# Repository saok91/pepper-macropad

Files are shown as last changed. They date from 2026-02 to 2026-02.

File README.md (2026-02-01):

# pepper – Custom Macropad PCB

This repository contains the **source design files** for **pepper**, a custom mechanical macropad designed using **KiCad**.

## Repository Contents

### Source files (tracked)
These files are the **source of truth** for the design and are version-controlled:

- `pepper.kicad_sch` – Schematic
- `pepper.kicad_pcb` – PCB layout
- `pepper.kicad_pro` – KiCad project configuration

### Generated files (ignored)
The following files are intentionally **not tracked** via `.gitignore`:

- 3D exports: `*.stl`, `*.step`, `*.stp`, `*.wrl`, `*.obj`
- Fabrication outputs: Gerbers, drills, pick-and-place files
- KiCad autosave, backup, and cache files
- BOM exports (`.csv`, `.xlsx`)
- OS / editor temporary files

Generated outputs may be shared separately (e.g. releases) when the design is ready.

## Tools

- **EDA**: KiCad (v7+ recommended)
- **Version control**: Git

## Project Status

- Work in progress (WIP)
- Not yet released for manufacturing

## Notes

- This repository contains **design sources only**
- Do not manufacture or modify outputs without validating against the KiCad source files

## License

TBD

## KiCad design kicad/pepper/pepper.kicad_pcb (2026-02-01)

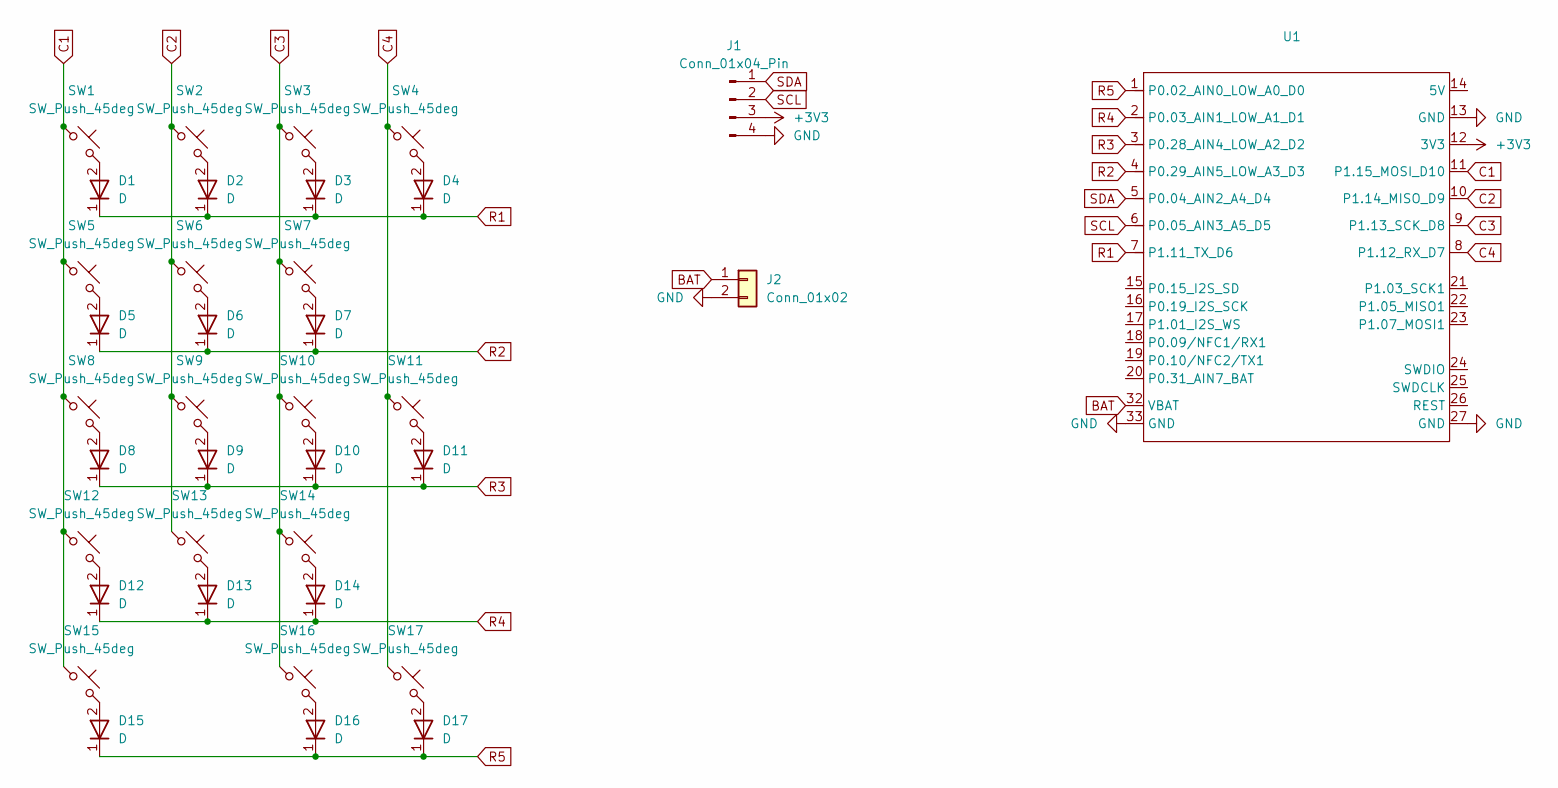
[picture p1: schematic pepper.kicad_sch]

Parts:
D1, D2, D3, D4, D5, D6, D7, D8, D9, D10, D11, D12, D13, D14, D15, D16, D17: D; D_SOD-123
J1: Conn_01x04_Pin; SSD1306
J2: Conn_01x02; JST_XH_S2B-XH-A_1x02_P2.50mm_Horizontal
SW1, SW2, SW3, SW4, SW5, SW6, SW7, SW8, SW9, SW10, SW12, SW13, SW14, SW16: SW_Push_45deg; MNP_SW_Hotswap_Kailh_MX_1.00u
SW11, SW17: SW_Push_45deg; MNP_SW_Hotswap_Kailh_MX_2.00u_90deg
SW15: SW_Push_45deg; MNP_SW_Hotswap_Kailh_MX_2.00u
U1: XIAO-nRF52840-Plus-SMD

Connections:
+3V3: J1.3, U1.12 (3V3)
BAT: J2.1, U1.32 (VBAT)
C1: SW1.1, SW5.1, SW8.1, SW12.1, SW15.1, U1.11 (P1.15_MOSI_D10)
C2: SW2.1, SW6.1, SW9.1, SW13.1, U1.10 (P1.14_MISO_D9)
C3: SW3.1, SW7.1, SW10.1, SW14.1, SW16.1, U1.9 (P1.13_SCK_D8)
C4: SW4.1, SW11.1, SW17.1, U1.8 (P1.12_RX_D7)
GND: J1.4, J2.2, U1.13 (GND), U1.27 (GND), U1.33 (GND)
unnamed: D1.2 (A), SW1.2
unnamed: D2.2 (A), SW2.2
unnamed: D3.2 (A), SW3.2
unnamed: D4.2 (A), SW4.2
unnamed: D5.2 (A), SW5.2
unnamed: D6.2 (A), SW6.2
unnamed: D7.2 (A), SW7.2
unnamed: D8.2 (A), SW8.2
unnamed: D9.2 (A), SW9.2
unnamed: D10.2 (A), SW10.2
unnamed: D11.2 (A), SW11.2
unnamed: D12.2 (A), SW12.2
unnamed: D13.2 (A), SW13.2
unnamed: D14.2 (A), SW14.2
unnamed: D15.2 (A), SW15.2
unnamed: D16.2 (A), SW16.2
unnamed: D17.2 (A), SW17.2
R1: D1.1 (K), D2.1 (K), D3.1 (K), D4.1 (K), U1.7 (P1.11_TX_D6)
R2: D5.1 (K), D6.1 (K), D7.1 (K), U1.4 (P0.29_AIN5_LOW_A3_D3)
R3: D8.1 (K), D9.1 (K), D10.1 (K), D11.1 (K), U1.3 (P0.28_AIN4_LOW_A2_D2)
R4: D12.1 (K), D13.1 (K), D14.1 (K), U1.2 (P0.03_AIN1_LOW_A1_D1)
R5: D15.1 (K), D16.1 (K), D17.1 (K), U1.1 (P0.02_AIN0_LOW_A0_D0)
SCL: J1.2, U1.6 (P0.05_AIN3_A5_D5)
SDA: J1.1, U1.5 (P0.04_AIN2_A4_D4)

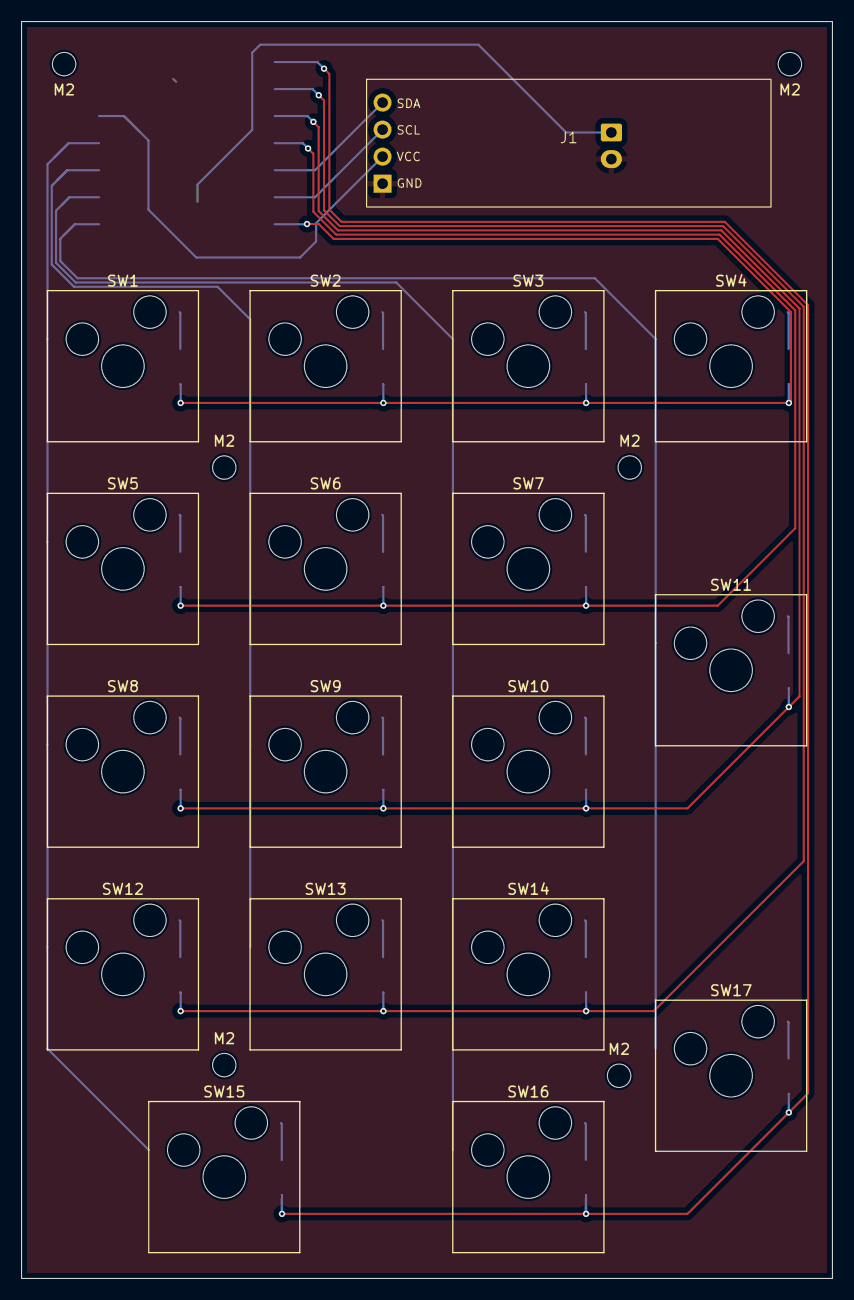
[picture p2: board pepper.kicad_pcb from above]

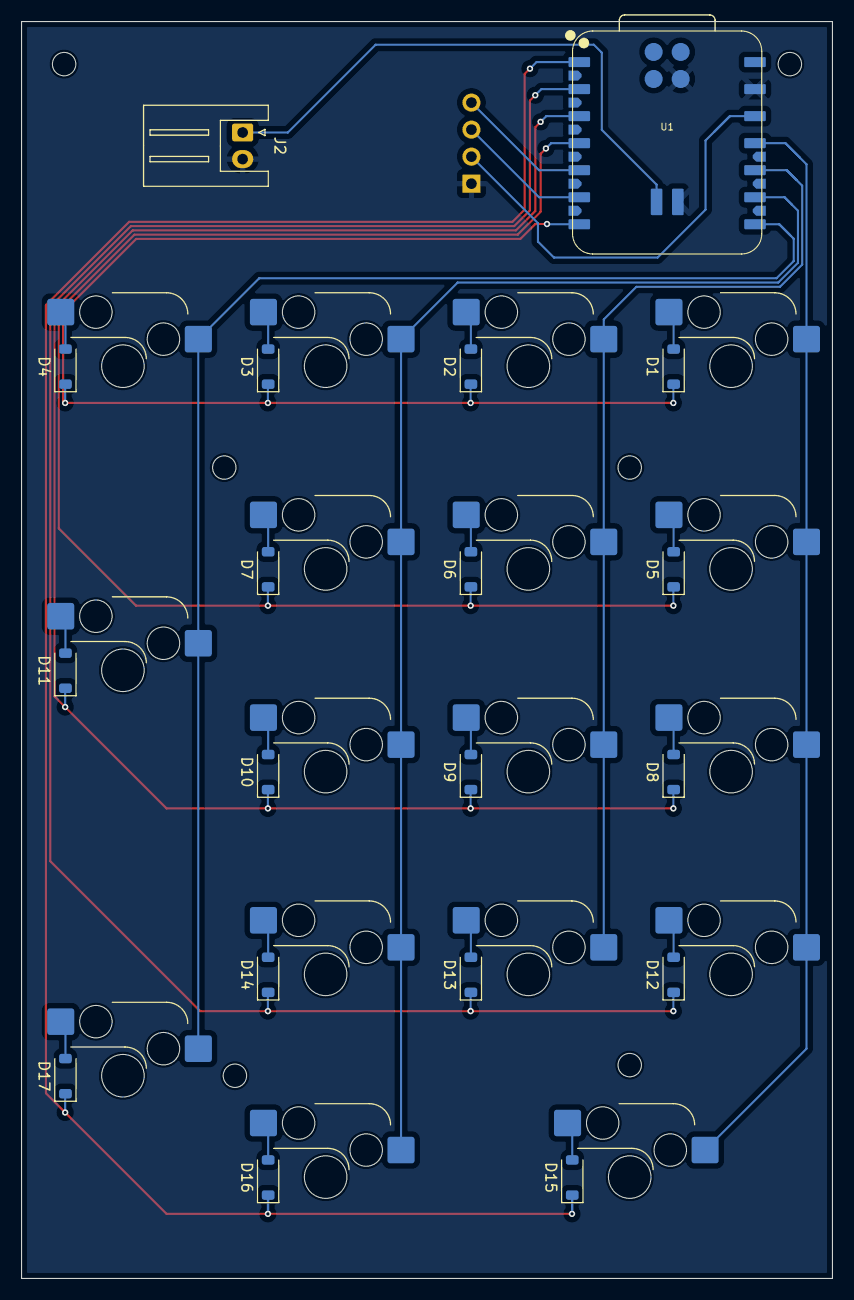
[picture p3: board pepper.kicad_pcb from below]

Board: 2 copper layers, 76.2 x 118.1 mm, 43 parts (19 on the bottom side), 31 nets.

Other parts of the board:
M2, M2#2, M2#3, M2#4, M2#5, M2#6: MountingHole_2.2mm_M2
